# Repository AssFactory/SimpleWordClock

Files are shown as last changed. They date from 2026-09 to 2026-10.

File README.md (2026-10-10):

# 🕒 Simple Word Clock (Swabian Edition)

A modern, embedded German word clock built on **Zephyr RTOS**, featuring a **Swabian dialect front matrix** ("Viertel x", "Halb x", etc.).

Designed for high-precision timekeeping, automatic brightness adjustment, and addressable RGB LED control, making it an ideal DIY wall or desktop clock.

---

## ✨ Features

* **Swabian Dialect Matrix:** Unique layout displaying time in authentic Swabian phrasing.
* **Hardware Flexible (Zephyr RTOS):** Highly portable across various microcontrollers (ESP32, STM32, NXP, etc.) thanks to Zephyr's Devicetree abstraction.
* **Automated Brightness:** Features a **BH1750** ambient light sensor to seamlessly adjust LED brightness according to room lighting.
* **Precise Timekeeping:** High-precision **DS3231 RTC** module with battery backup ensures reliable timekeeping across power interruptions.
* **Addressable LED Matrix:** Driven by **WS2812B** RGB LEDs (60 LEDs/m density).
* **Robust Firmware:** Built on **Zephyr RTOS 4.4.2**.

---

## 🖨️ 3D Printed Parts & Enclosure

The enclosure, front matrix grid, and diffuser plates are optimized for 3D printing.

* 📐 **STL Files:** Download printable files from the [Releases](../../releases) section.
* **Material Recommendation:** **PETG** is highly recommended for mechanical stability and durability.
  * *Tested Setup:* Black PETG (chassis & matrix grid) + transparent PETG (diffuser layer).

---

## 🛠️ Bill of Materials (BOM)

### Electronics & Hardware

| Component | Description | Notes / Selection Rationale |
| :--- | :--- | :--- |
| **Adafruit ItsyBitsy RP2040** | Main microcontroller board running Zephyr RTOS. | **Selected because** it includes an onboard **74HCT125 level shifter**, which is highly recommended for driving the required 5V logic signal of WS2812B LEDs without extra components. |
| **WS2812B LED Strip** | 60 LEDs/m density (~104 LEDs / approx. 2 meters needed). | Required |
| **DS3231 RTC Module** | High-precision I2C real-time clock with coin cell backup. | Required |
| **BH1750 Sensor** | Digital ambient light sensor (I2C interface). | Required |
| **Fuse Holder & Fuse** | Panel-mount inline fuse holder for power safety protection. | Required |
| **DC Jack Panel Mount** | Standard 5.5mm x 2.1mm DC barrel jack for 5V power supply. | Required |
| **Acrylic Front Plate** | Approx. 300 mm diameter clear/smoked acrylic panel. | Optional |
| **Mirrored Window Film** | One-way mirror or window tint film for contrast enhancement. | Optional |

---

## 🔌 Hardware Connections & Pinout

Standard signal wiring as configured in the Zephyr Devicetree:

| Peripheral | Module Pin | Board Pin | Protocol / Notes |
| :--- | :--- | :--- | :--- |
| **DS3231 RTC** | SDA / SCL | I2C0 SDA / SCL | Shared I2C Bus |
| **BH1750 Sensor** | SDA / SCL | I2C0 SDA / SCL | Shared I2C Bus |
| **WS2812B Strip** | Data Input | Pin 5 (5V Logic Out) | Driven directly via the onboard level shifter |
| **Power Input** | 5V / GND | 5V / GND | Powered via DC Jack & fuse |

---

## 💻 Development Environment & Build

This project runs on **Zephyr RTOS 4.4.2**, managed using **West** and **CMake** (T2 Application Repository topology).

### Prerequisites

Follow the official [Zephyr Getting Started Guide](https://docs.zephyrproject.org/latest/develop/getting_started/index.html) to set up host tools (Python, CMake, Ninja, Git, Device Tree Compiler, and the Zephyr SDK toolchain) for Windows, macOS, or Linux.

### Setup & Build Steps

1. **Clone the Application Repository**
   ```bash
   git clone https://github.com/AssFactory/SimpleWordClock.git
   ```

2. **Create & Activate Python Virtual Environment**
   ```bash
   python -m venv .venv
   source .venv/Scripts/activate  # On Linux/macOS: source .venv/bin/activate
   ```

3. **Install West & Initialize Workspace**
   ```bash
   python -m pip install west
   west init -l
   west update
   ```

4. **Install Python Dependencies**
   ```bash
   west packages pip --install
   ```

5. **Build Firmware**
   ```bash
   west build -b adafruit_itsybitsy_rp2040 -p always
   ```

6. **Flash Target**
   Connect the board in bootloader mode (hold the `BOOTSEL` button while plugging in USB)
   ```bash
   west flash
   ```
---

## 🤝 Contributing

Contributions, bug reports, and feature requests are welcome! Feel free to check out the [issues page](../../issues) or submit a pull request.

---

## 📝 License

This project is open-source software licensed under the [MIT License](LICENSE).

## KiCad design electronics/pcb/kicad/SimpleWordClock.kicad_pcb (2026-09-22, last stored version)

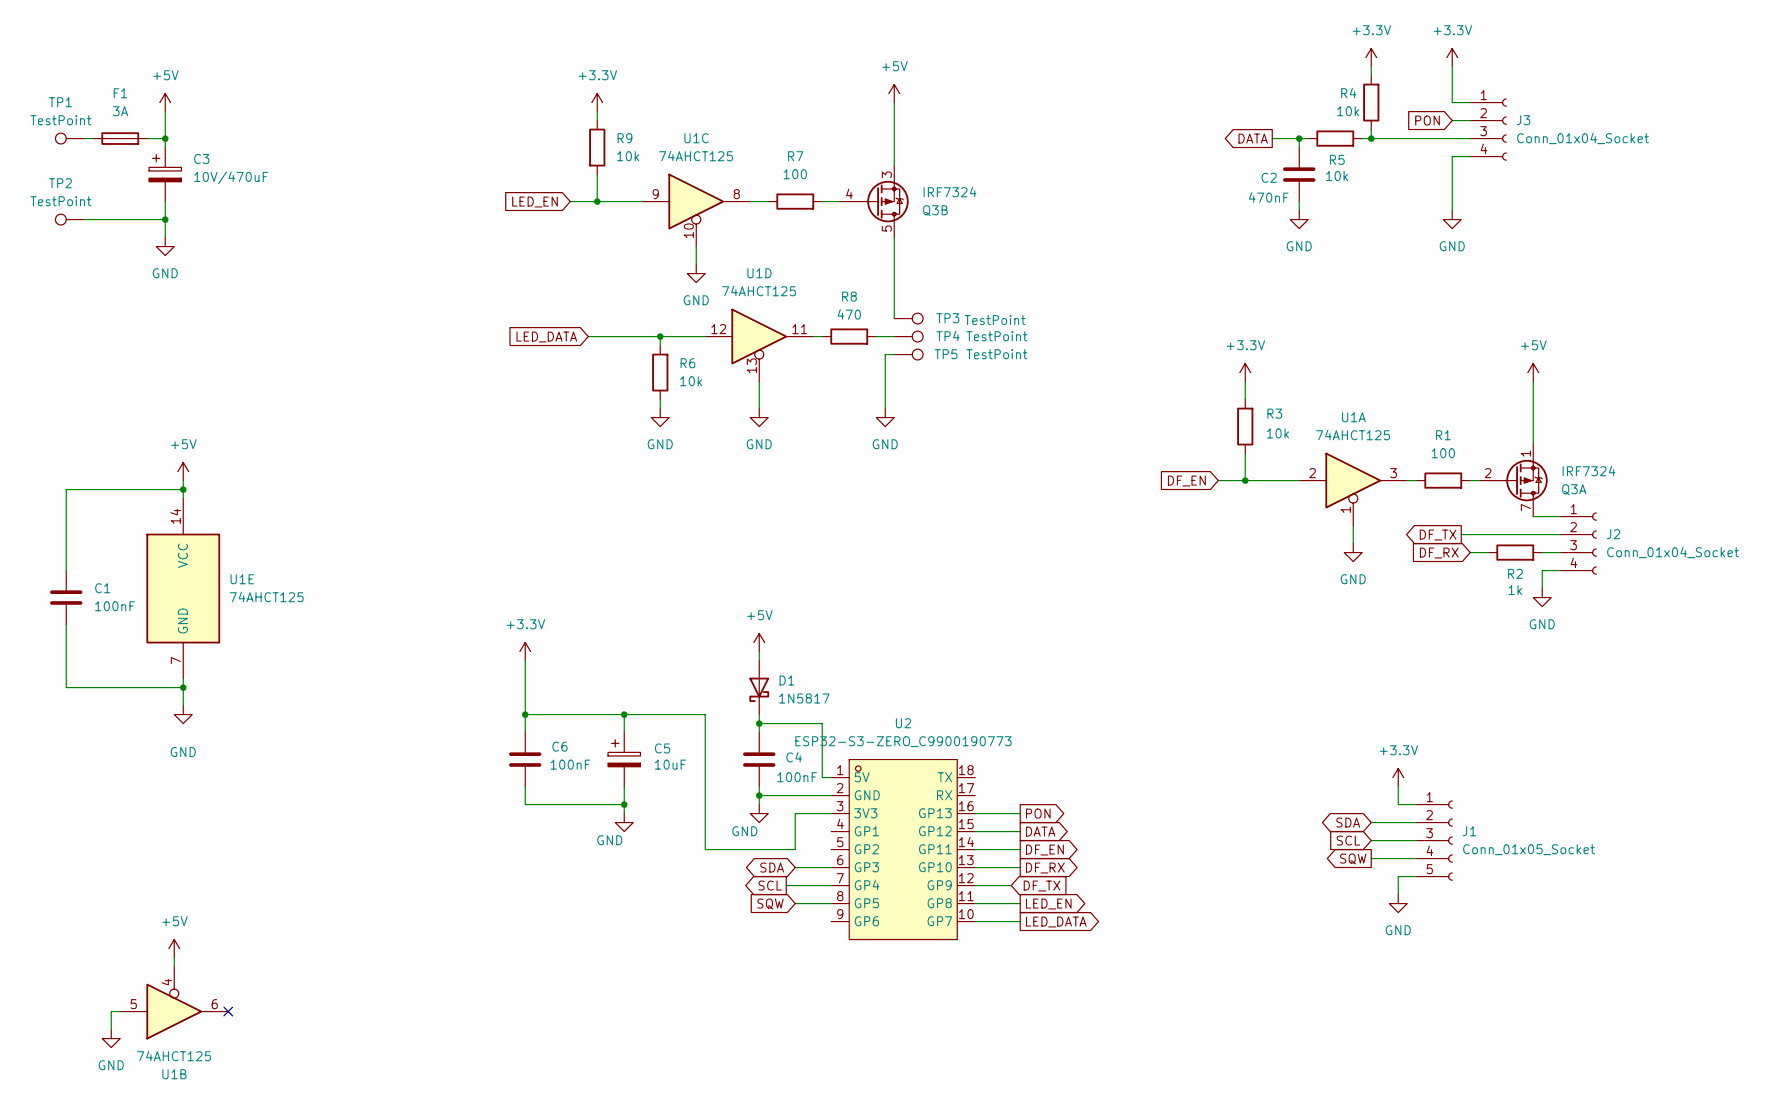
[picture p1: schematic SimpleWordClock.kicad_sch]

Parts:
C1, C4, C6: 100nF; C_1210_3225Metric_Pad1.33x2.70mm_HandSolder
C2: 470nF; C_1206_3216Metric_Pad1.33x1.80mm_HandSolder
C3: 10V/470uF; CP_Elec_10x10.5
C5: 10uF; CP_Elec_10x10
D1: 1N5817; D_DO-41_SOD81_P10.16mm_Horizontal
F1: 3A; Fuseholder_Clip-5x20mm_Schurter_CQM_Inline_P20.60x5.00mm_D1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
J1: Conn_01x05_Socket; JST_EH_B5B-EH-A_1x05_P2.50mm_Vertical
J2, J3: Conn_01x04_Socket; JST_EH_B4B-EH-A_1x04_P2.50mm_Vertical
Q3: IRF7324; SOIC-8_3.9x4.9mm_P1.27mm
R1, R7: 100; R_1210_3225Metric_Pad1.30x2.65mm_HandSolder
R2: 1k; R_1210_3225Metric_Pad1.30x2.65mm_HandSolder
R3, R4, R5, R6, R9: 10k; R_1210_3225Metric_Pad1.30x2.65mm_HandSolder
R8: 470; R_1210_3225Metric_Pad1.30x2.65mm_HandSolder
TP1, TP2, TP3, TP5: TestPoint; TestPoint_Pad_4.0x4.0mm
TP4: TestPoint; TestPoint_Pad_3.0x3.0mm
U1: 74AHCT125; DIP-14_W7.62mm_LongPads
U2: ESP32-S3-ZERO_C9900190773; COMM-SMD_18P-L24.5-W17.8-P2.54_ESP32-S3-ZERO; MPN ESP32-S3-Zero; LCSC Part C9900190773

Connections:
+3.3V: C5.1, C6.1, J1.1, J3.1, R3.2, R4.2, R9.1, U2.3 (3V3)
+5V: C1.1, C3.1, D1.2 (A), F1.2, Q3.1 (S1), Q3.3 (S2), U1.4, U1.14 (VCC)
DATA: C2.1, R5.1, U2.15 (GP12)
DF_EN: R3.1, U1.2, U2.14 (GP11)
DF_RX: R2.1, U2.13 (GP10)
DF_TX: J2.2, U2.12 (GP9)
GND: C1.2, C2.2, C3.2, C4.2, C5.2, C6.2, J1.5, J2.4, J3.4, R6.1, TP2.1 (1_1), TP5.1 (1_1), U1.1, U1.5, U1.7 (GND), U1.10, U1.13, U2.2 (GND)
LED_DATA: R6.2, U1.12, U2.10 (GP7)
LED_EN: R9.2, U1.9, U2.11 (GP8)
unnamed: C4.1, D1.1 (K), U2.1 (5V)
unnamed: F1.1, TP1.1 (1_1)
unnamed: J2.1, Q3.7 (D1), Q3.8 (D1)
unnamed: J2.3, R2.2
unnamed: J3.3, R4.1, R5.2
unnamed: Q3.2 (G1), R1.2
unnamed: Q3.5 (D2), Q3.6 (D2), TP3.1 (1_1)
unnamed: Q3.4 (G2), R7.2
unnamed: R1.1, U1.3
unnamed: R7.1, U1.8
unnamed: R8.1, U1.11
unnamed: R8.2, TP4.1 (1_1)
PON: J3.2, U2.16 (GP13)
SCL: J1.3, U2.7 (GP4)
SDA: J1.2, U2.6 (GP3)
SQW: J1.4, U2.8 (GP5)

Board: 2 copper layers, 28 parts (0 on the bottom side), 25 nets, no tracks yet.

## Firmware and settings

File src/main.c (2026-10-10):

#include <zephyr/kernel.h>
#include <zephyr/sys/printk.h>
#include <stdint.h>

#include "timeprocess/timeprocess.h"
#include "ambiente/ambiente.h"
#include "display/display.h"

/* Thread intervals */
#define TIMEPROCESS_INTERVAL_MS  1000U
#define AMBIENTE_INTERVAL_MS     1000U

/* Thread stack sizes */
#define TIMEPROCESS_STACK_SIZE   1024
#define AMBIENTE_STACK_SIZE      1024

/* Thread priorities: lower number means higher priority */
#define TIMEPROCESS_PRIORITY     6
#define AMBIENTE_PRIORITY        6

K_THREAD_STACK_DEFINE(timeprocess_stack, TIMEPROCESS_STACK_SIZE);
K_THREAD_STACK_DEFINE(ambiente_stack, AMBIENTE_STACK_SIZE);

static struct k_thread timeprocess_thread_data;
static struct k_thread ambiente_thread_data;

/* Thread arguments must remain valid for the thread lifetime. */
static const uint32_t timeprocess_interval_ms =
    TIMEPROCESS_INTERVAL_MS;

static const uint32_t ambiente_interval_ms =
    AMBIENTE_INTERVAL_MS;

int main(void)
{
    int ret = display_init();

    if (ret < 0) {
        printk("Display initialization failed: %d\n", ret);
        return ret;
    }

    k_thread_create(
        &timeprocess_thread_data,
        timeprocess_stack,
        K_THREAD_STACK_SIZEOF(timeprocess_stack),
        timeprocess_thread,
        (void *)&timeprocess_interval_ms,
        NULL,
        NULL,
        TIMEPROCESS_PRIORITY,
        0,
        K_NO_WAIT
    );

    k_thread_create(
        &ambiente_thread_data,
        ambiente_stack,
        K_THREAD_STACK_SIZEOF(ambiente_stack),
        ambiente_thread,
        (void *)&ambiente_interval_ms,
        NULL,
        NULL,
        AMBIENTE_PRIORITY,
        0,
        K_NO_WAIT
    );

    return 0;
}

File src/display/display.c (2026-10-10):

#include <zephyr/logging/log.h>
#include <zephyr/devicetree.h>
#include <zephyr/kernel.h>
#include <zephyr/device.h>
#include <zephyr/drivers/led_strip.h>
#include <zephyr/shell/shell.h>
#include <zephyr/sys/util.h>

#include <errno.h>
#include <stdint.h>
#include <stddef.h>

#include "display.h"

LOG_MODULE_REGISTER(display, LOG_LEVEL_INF);

#define LED_STRIP_NODE DT_ALIAS(led_strip)
#define LED_COUNT DT_PROP(LED_STRIP_NODE, chain_length)

#define LED_NONE UINT8_MAX

#define DISPLAY_WIDTH  12
#define DISPLAY_HEIGHT 10

#define LED_STRIP_MIN_BRIGHTNESS 10
#define LED_STRIP_MAX_BRIGHTNESS 200

#define LED_STRIP_MAX_CURRENT 2500
#define LED_STRIP_IDLE_CURRENT 100
#define LED_MAX_CURRENT_PER_CHANNEL 20

/* Dedicated display work queue */
#define DISPLAY_WORKQ_STACK_SIZE 2048
#define DISPLAY_WORKQ_PRIORITY   5

K_THREAD_STACK_DEFINE(display_workq_stack,
                      DISPLAY_WORKQ_STACK_SIZE);

static struct k_work_q display_workq;

/* Signal that the LED test has finished */
K_SEM_DEFINE(led_test_done, 0, 1);

/* Prevent multiple simultaneous LED test requests */
K_MUTEX_DEFINE(led_test_mutex);

/* Work handlers */
static void display_update_handler(struct k_work *work);
static void display_led_test_handler(struct k_work *work);

/* Internal function declaration */
static int display_update(void);

/* Work items */
K_WORK_DEFINE(display_update_work, display_update_handler);
K_WORK_DEFINE(display_led_test_work, display_led_test_handler);

/*
 * Gamma correction lookup table.
 * Reference:
 * https://learn.adafruit.com/led-tricks-gamma-correction/the-quick-fix
 */
static const uint8_t gamma_table[256] = {
    0,  0,  0,  0,  0,  0,  0,  0,  0,  0,  0,  0,  0,  0,  0,  0,
    0,  0,  0,  0,  0,  0,  0,  0,  0,  0,  0,  0,  1,  1,  1,  1,
    1,  1,  1,  1,  1,  1,  1,  1,  1,  2,  2,  2,  2,  2,  2,  2,
    2,  3,  3,  3,  3,  3,  3,  3,  4,  4,  4,  4,  4,  5,  5,  5,
    5,  6,  6,  6,  6,  7,  7,  7,  7,  8,  8,  8,  9,  9,  9, 10,
    10, 10, 11, 11, 11, 12, 12, 13, 13, 13, 14, 14, 15, 15, 16, 16,
    17, 17, 18, 18, 19, 19, 20, 20, 21, 21, 22, 22, 23, 24, 24, 25,
    25, 26, 27, 27, 28, 29, 29, 30, 31, 32, 32, 33, 34, 35, 35, 36,
    37, 38, 39, 39, 40, 41, 42, 43, 44, 45, 46, 47, 48, 49, 50, 50,
    51, 52, 54, 55, 56, 57, 58, 59, 60, 61, 62, 63, 64, 66, 67, 68,
    69, 70, 72, 73, 74, 75, 77, 78, 79, 81, 82, 83, 85, 86, 87, 89,
   90, 92, 93, 95, 96, 98, 99,101,102,104,105,107,109,110,112,114,
  115,117,119,120,122,124,126,127,129,131,133,135,137,138,140,142,
  144,146,148,150,152,154,156,158,160,162,164,167,169,171,173,175,
  177,180,182,184,186,189,191,193,196,198,200,203,205,208,210,213,
  215,218,220,223,225,228,231,233,236,239,241,244,247,249,252,255
};

/* Map logical grid coordinates to physical LED indices */
static const uint8_t led_map[DISPLAY_WIDTH * DISPLAY_HEIGHT] = {
    /* X:       0         1         2         3    4    5    6    7    8         9        10        11 */
    /* Y 0 */ LED_NONE, LED_NONE, LED_NONE, 103, 102, 101, 100,  99,  98, LED_NONE, LED_NONE, LED_NONE,
    /* Y 1 */ LED_NONE,       88,       89,  90,  91,  92,  93,  94,  95,       96,       97, LED_NONE,
    /* Y 2 */       87,       86,       85,  84,  83,  82,  81,  80,  79,       78,       77,       76,
    /* Y 3 */       64,       65,       66,  67,  68,  69,  70,  71,  72,       73,       74,       75,
    /* Y 4 */       63,       62,       61,  60,  59,  58,  57,  56,  55,       54,       53,       52,
    /* Y 5 */       40,       41,       42,  43,  44,  45,  46,  47,  48,       49,       50,       51,
    /* Y 6 */       39,       38,       37,  36,  35,  34,  33,  32,  31,       30,       29,       28,
    /* Y 7 */       16,       17,       18,  19,  20,  21,  22,  23,  24,       25,       26,       27,
    /* Y 8 */ LED_NONE,       15,       14,  13,  12,  11,  10,   9,   8,        7,        6, LED_NONE,
    /* Y 9 */ LED_NONE, LED_NONE, LED_NONE,   0,   1,   2,   3,   4,   5, LED_NONE, LED_NONE, LED_NONE
};

static const struct device *const led_strip = DEVICE_DT_GET(LED_STRIP_NODE);

/* Logical pixel buffer and physical output buffer */
static struct led_rgb pixels[LED_COUNT];
static struct led_rgb output_pixels[LED_COUNT];

static uint8_t brightness = LED_STRIP_MAX_BRIGHTNESS;

/*
 * Initialize the display and start its dedicated work queue.
 */
int display_init(void)
{
    if (!device_is_ready(led_strip)) {
        LOG_ERR("LED strip is not ready");
        return -ENODEV;
    }

    k_work_queue_start(&display_workq,
                       display_workq_stack,
                       K_THREAD_STACK_SIZEOF(display_workq_stack),
                       DISPLAY_WORKQ_PRIORITY,
                       NULL);

    LOG_INF("Display initialized");
    return 0;
}

/*
 * Execute a normal display update from the display work queue.
 */
static void display_update_handler(struct k_work *work)
{
    ARG_UNUSED(work);

    int ret = display_update();

    if (ret < 0) {
        LOG_ERR("Display update failed: %d", ret);
    }
}

/*
 * Request a normal display update.
 * Multiple requests can be coalesced by the work queue.
 */
int display_request_update(void)
{
    int ret = k_work_submit_to_queue(&display_workq,
                                     &display_update_work);

    if (ret < 0) {
        LOG_ERR("Failed to submit display update: %d", ret);
    }

    return ret;
}
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

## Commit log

2026-09-22 add kicad projekt
    [SimpleWordClock.kicad_pcb, SimpleWordClock.kicad_sch]
2026-10-06 clean up
    [SimpleWordClock.kicad_pcb, SimpleWordClock.kicad_sch]
2026-10-10 add basic application structure 2 thread work queue for display update
2026-10-11 fix chain length
2026-10-11 chnage ambinete thread intervall
2026-10-22 add check if thread was created
2026-10-31 Update GitHub Actions to Node 24
    Append the tagged commit hash to firmware versions and pin Ubuntu 24.04 for reproducible workflows.
2026-11-01 low down software current limit
2026-11-02 add shell function for current
2026-11-04 kalbbrate current estimation
